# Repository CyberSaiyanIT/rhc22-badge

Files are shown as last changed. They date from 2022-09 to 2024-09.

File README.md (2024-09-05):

# RHC22 Badge

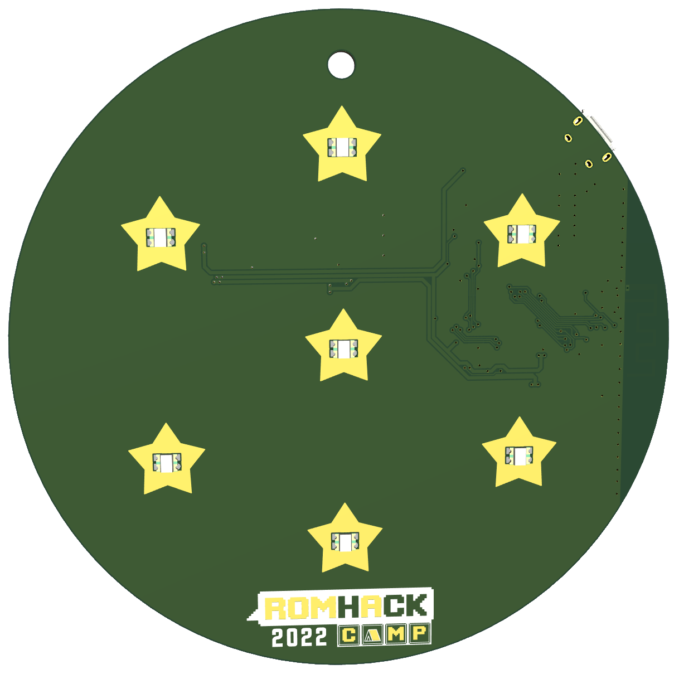
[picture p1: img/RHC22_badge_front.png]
RHC22 badge front

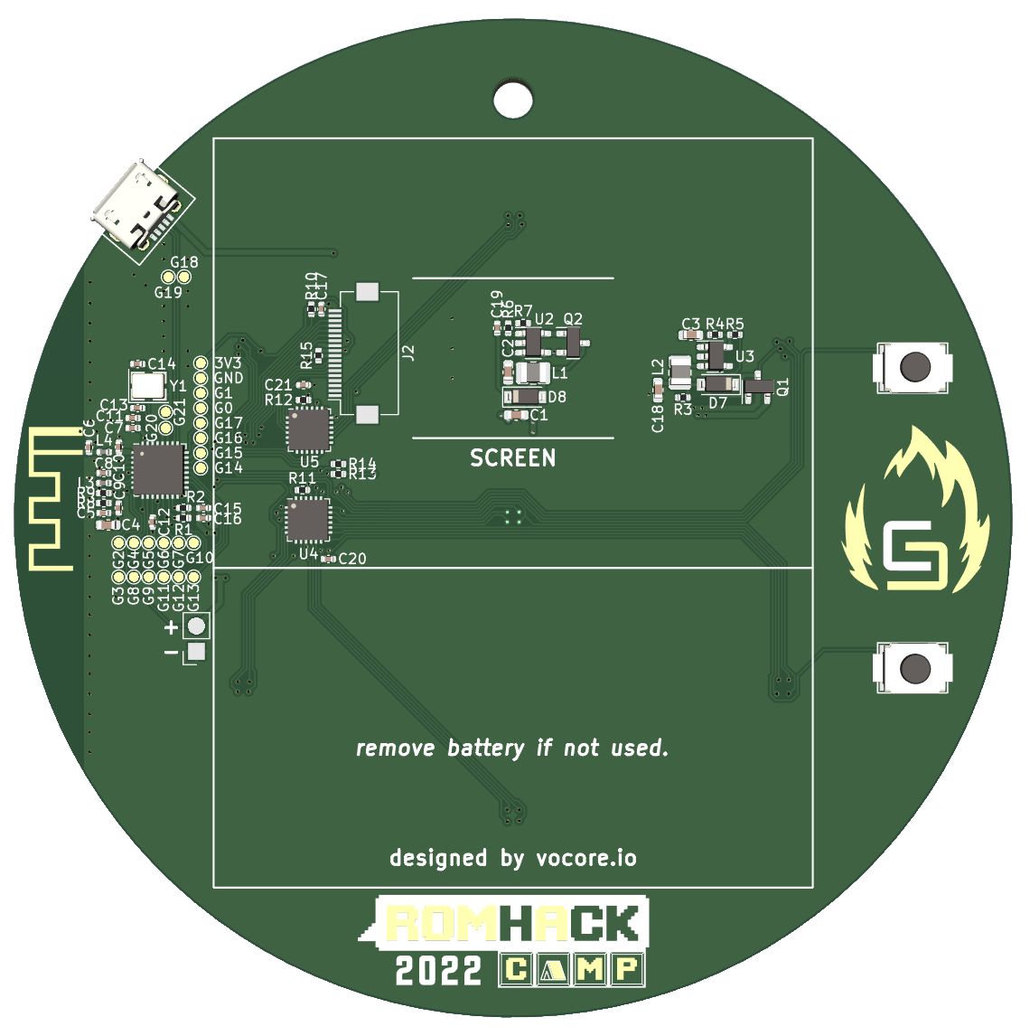
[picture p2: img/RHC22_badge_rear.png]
RHC22 badge rear


Cyber Saiyan community has designed and developed a special gadget to celebrate RomHack Camp 2022.

You can grab the badge by purchasing it at the Cyber Saiyan tent during the Camp and the Conference
* The badge's package will include a lanyard, two batteries and...the badge
* In order to start playing around with and hacking it, is recommended to bring a micro USB data cable with you
* It is also recommended to bring replacement 1.5V AA batteries and/or a powerbank
* The badge is already flashed with the Cyber Saiyan firmware
* We really will appreciate any improvement to the project and pull requests
* Don't hesitate to come and visit us at the Cyber Saiyan tent if you need help

## Features

The badge has some very simple features that will improve your Camp experience:
* It is designed to recall the dragon spheres (maybe you will be able to summon Shenron too)
* The base SOC is a single core ESP32-C3 
   * Integrates a 32-bit core RISC-V microcontroller with a maximum clock speed of 160 MHz
   * 22 configurable GPIOs
   * 400 KB of internal RAM and 4MB flash
   * WiFi and Bluetooth 5
* In the front there are 7 RGB leds
* In the back you have  
   * Two push buttons; use your nail for a better experience :)
   * A 2.4'' TFT screen 
   * A two AA battery holder

Once powered the badge will be assigned a 1-7 ID and will start to advertise itself using BLE and the screen will show the RomHack Camp 2022 logo 
* You can move to next/prev screen by a 1s long press
* The 1st screen is the RHC22 schedule: 
   * You will be able to read the schedule of the Camp (use the 4th screen to update it)
* The 2nd screen is the badges' radar: 
   * You will see all the badges around you in a dragon ball style
* The 3rd screen is the badge's list: 
   * You will see all the badges around you in a table view
* The 4th screen is for the WiFI functionalities: 
   * Start the AP mode and connect with your PC/smartphone in order to explore more functionalities
   * Start the schedule SYNC mode in order to update the schedule at the 2nd screen
* The 5th screen is for fun (you will be able to play with snake)

# Toolchain setup

## Prepare the environment 

### Visual Studio Code (VSCode)
Install Visual Studio Code as development environment:

* https://code.visualstudio.com/ - follow instructions there, if you don't have vscode yet.

### PlatformIO (PIO) extension
Install PlatformIO extension on Visual Studio Code:

* [Installation](http://docs.platformio.org/page/ide/vscode.html)
* [Quick Start](http://docs.platformio.org/page/ide/vscode.html#quick-start)
* [User Guide](http://docs.platformio.org/page/ide/vscode.html#user-guide)

Please follow to the official documentation [PlatformIO IDE for VSCode](http://docs.platformio.org/page/ide/vscode.html).

## Setup the project

* Git clone this repository and open it on VSCode

## Build www data (Linux)

* ./www-build.sh

## Build www data (Docker)

* Install docker
* docker build --pull --rm -f "Dockerfile" -t rhc22badge:latest "."
* (Bash) docker run -it -v <span>$</span>(pwd)/public:/public -v <span>$</span>(pwd)/data/www:/output rhc22badge
* (Powershell) docker run -it -v <span>$</span>{PWD}/public:/public -v <span>$</span>{PWD}/data/www:/output rhc22badge
   
## Build/Upload Filesystem

In order to upload the filesystem to the badge you need to plugin the badge using USB.
In the "Project Tasks" view of PIO navigate to:

* RHC22-Bagde
   * Platform
      * Build Filesystem Image
      * Upload Filesystem Image

## Build/Upload Firmware
In order to upload the firmware to the badge you need to plugin the badge using USB.
In the "Project Tasks" view of PIO navigate to:

* RHC22-Bagde
   * General
      * Build
      * Upload

# Known Issues
* after dowloading the MOCA schedule from web you should restart the badge to see the updated schedule. This is due to a memory allocartion problem (the json file is too big) and the fix is a WIP

# Misc

## Use a different logo image

To use a different logo first you need to 
* convert the BMP/JPG/PNG/SVG file to a C array; you can do this using an [online image converter](https://lvgl.io/tools/imageconverter) setting CF_TRUE_COLOR_ALPHA option
* adjust [main/badge/common/img_logo.c](main/badge/common/img_logo.c) file

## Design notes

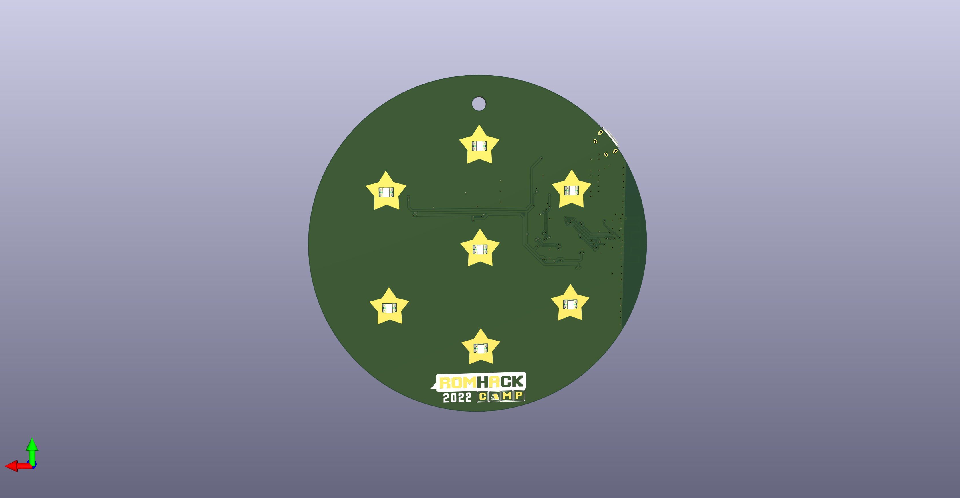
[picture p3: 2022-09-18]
hardware/dragon-front.png

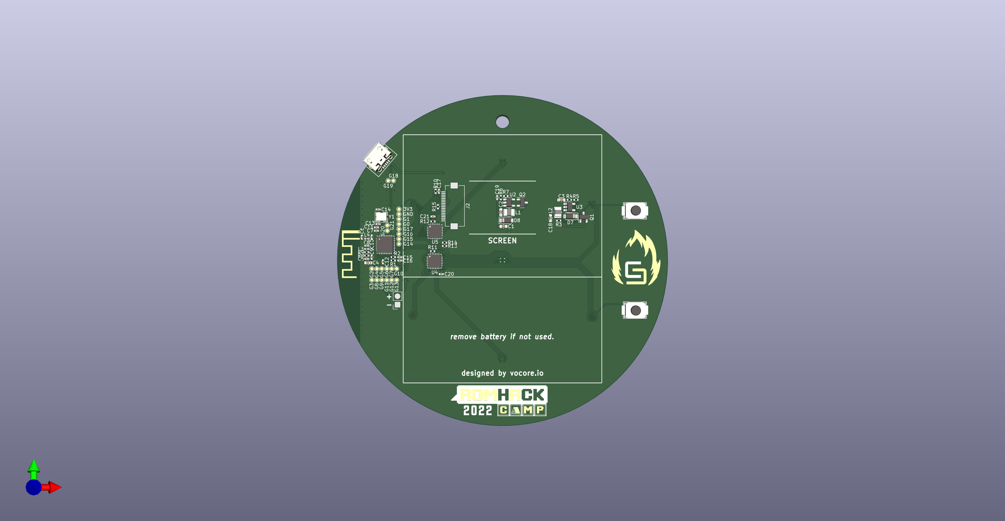
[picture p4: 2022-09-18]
hardware/dragon-back.png

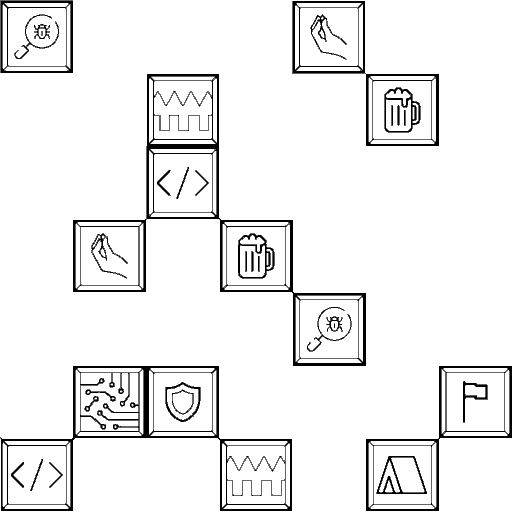
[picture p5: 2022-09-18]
public/img/sx.gif

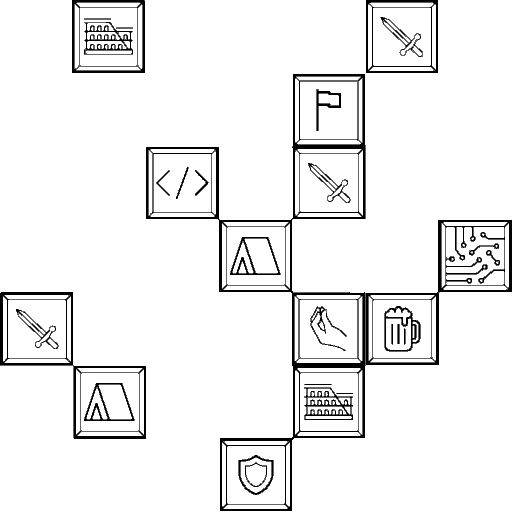
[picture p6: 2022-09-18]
public/img/dx.gif

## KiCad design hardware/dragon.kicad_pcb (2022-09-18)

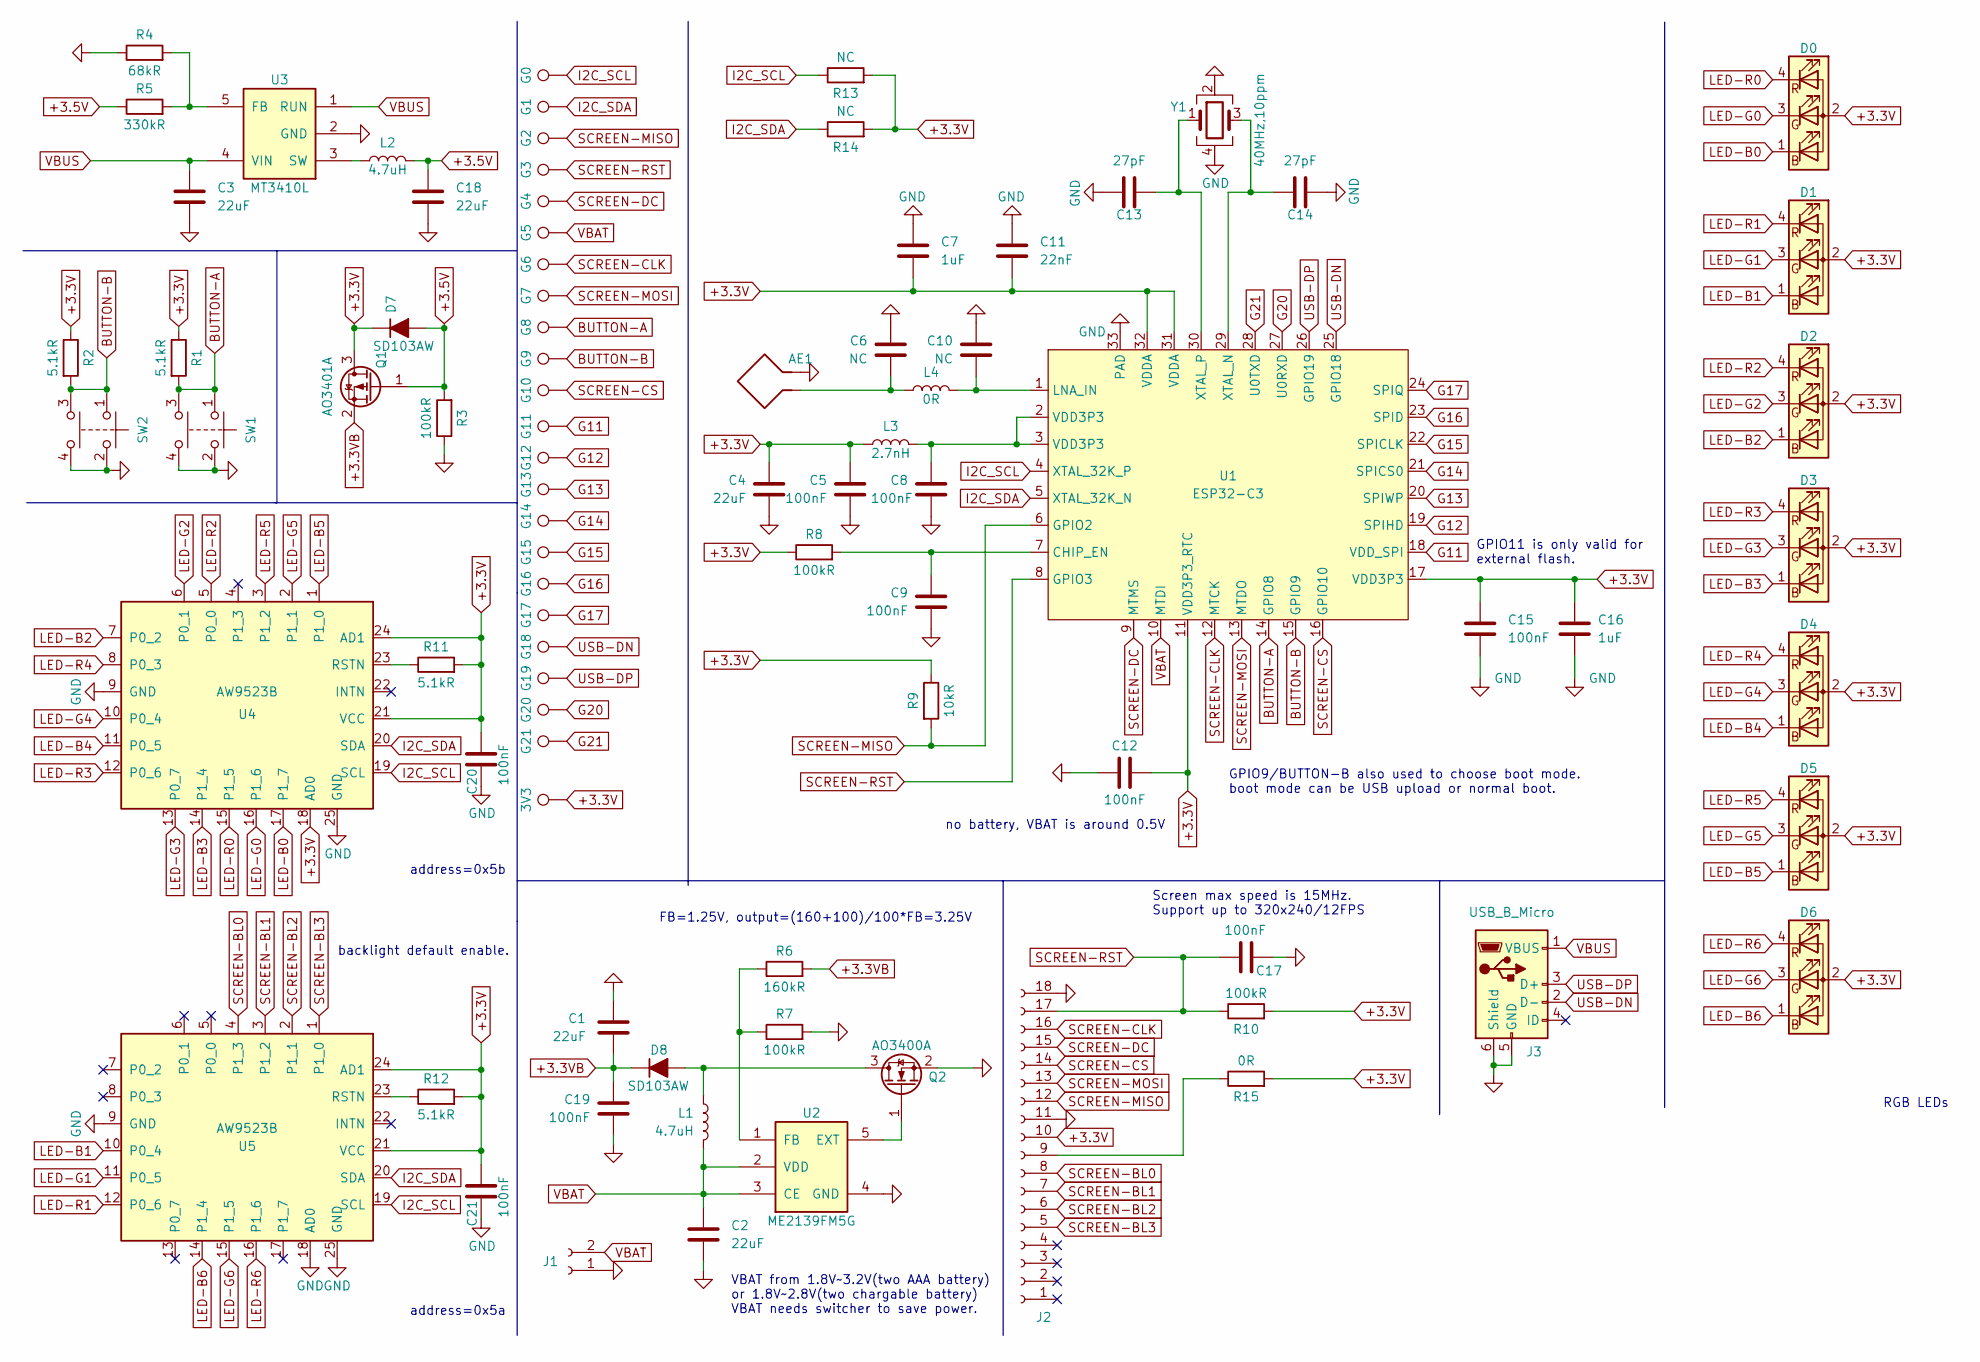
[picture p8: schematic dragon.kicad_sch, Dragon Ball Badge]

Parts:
3V3: TestPoint; TestPoint_Pad_D1.0mm
AE1: Antenna_Loop; Texas_SWRA117D_2.4GHz_Left
C1, C2, C3, C4, C18: 22uF; C_0603_1608Metric
C5, C8, C9, C12, C15, C17, C19, C20, C21: 100nF; C_0402_1005Metric
C6, C10: NC; C_0402_1005Metric
C7, C16: 1uF; C_0402_1005Metric
C11: 22nF; C_0402_1005Metric
C13, C14: 27pF; C_0402_1005Metric
D0, D1, D2, D3, D4, D5, D6: LED_BAGR
D7, D8: SD103AW; D_SOD-123
G0, G1, G2, G3, G4, G5, G6, G7, G8, G9, G10, G11, G12, G13, G14, G15, G16, G17, G18, G19, G20, G21: TestPoint; TestPoint_Pad_D1.0mm
J1: Conn_01x02_Female; PinSocket_1x02_P2.54mm_Vertical
J2: SCREEN; Hirose_FH12-18S-0.5SH_1x18-1MP_P0.50mm_Horizontal
J3: USB_B_Micro; USB_Micro-B
L1, L2: 4.7uH; L_1008_2520Metric
L3: 2.7nH; L_0402_1005Metric
L4: 0R; L_0402_1005Metric
Q1: AO3401A; SOT-23
Q2: AO3400A; SOT-23
R1, R2, R11, R12: 5.1kR; R_0402_1005Metric
R3, R7, R8, R10: 100kR; R_0402_1005Metric
R4: 68kR; R_0402_1005Metric
R5: 330kR; R_0402_1005Metric
R6: 160kR; R_0402_1005Metric
R9: 10kR; R_0402_1005Metric
R13, R14: NC; R_0402_1005Metric
R15: 0R; R_0402_1005Metric
SW1, SW2: SW_Push_Dual; BUTTON
U1: ESP32-C3; QFN-32-1EP_5x5mm_P0.5mm_EP3.1x3.1mm
U2: ME2139FM5G; SOT-23-5
U3: MT3410L; SOT-23-5
U4, U5: AW9523B; HVQFN-24-1EP_4x4mm_P0.5mm_EP2.6x2.6mm
Y1: 40MHz,10ppm; Crystal_SMD_3225-4Pin_3.2x2.5mm

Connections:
+3.3V: 3V3.1, C4.2, C5.2, C7.1, C11.1, C12.1, C15.2, C16.2, C20.2, C21.2, D0.2 (A), D1.2 (A), D2.2 (A), D3.2 (A), D4.2 (A), D5.2 (A), D6.2 (A), D7.1 (K), J2.10, L3.1, Q1.3 (D), R1.1, R2.1, R8.1, R9.1, R10.2, R11.2, R12.2, R13.2, R14.2, R15.2, U1.11 (VDD3P3_RTC), U1.17 (VDD3P3), U1.31 (VDDA), U1.32 (VDDA), U4.18 (AD0), U4.21 (VCC), U4.24 (AD1), U5.21 (VCC), U5.24 (AD1)
+3.3VB: C1.1, C19.2, D8.1 (K), Q1.2 (S), R6.2
+3.5V: C18.1, D7.2 (A), L2.2, Q1.1 (G), R3.2, R5.1
BUTTON-A: G8.1, R1.2, SW1.1, SW1.3, U1.14 (GPIO8)
BUTTON-B: G9.1, R2.2, SW2.1, SW2.3, U1.15 (GPIO9)
G11: G11.1, U1.18 (VDD_SPI)
G12: G12.1, U1.19 (SPIHD)
G13: G13.1, U1.20 (SPIWP)
G14: G14.1, U1.21 (SPICS0)
G15: G15.1, U1.22 (SPICLK)
G16: G16.1, U1.23 (SPID)
G17: G17.1, U1.24 (SPIQ)
G20: G20.1, U1.27 (U0RXD)
G21: G21.1, U1.28 (U0TXD)
GND: AE1.2, C1.2, C2.2, C3.2, C4.1, C5.1, C6.2, C7.2, C8.1, C9.1, C10.2, C11.2, C12.2, C13.1, C14.2, C15.1, C16.1, C17.2, C18.2, C19.1, C20.1, C21.1, J1.1, J2.11, J2.18, J3.5 (GND), J3.6 (Shield), Q2.2 (S), R3.1, R4.1, R7.2, SW1.2, SW1.4, SW2.2, SW2.4, U1.33 (PAD), U2.4 (GND), U3.2 (GND), U4.9 (GND), U4.25 (GND), U5.9 (GND), U5.18 (AD0), U5.25 (GND), Y1.2, Y1.4; also elsewhere on the board
I2C_SCL: G0.1, R13.1, U1.4 (XTAL_32K_P), U4.19 (SCL), U5.19 (SCL)
I2C_SDA: G1.1, R14.1, U1.5 (XTAL_32K_N), U4.20 (SDA), U5.20 (SDA)
LED-B0: D0.1 (BK), U4.17 (P1_7)
LED-B1: D1.1 (BK), U5.10 (P0_4)
LED-B2: D2.1 (BK), U4.7 (P0_2)
LED-B3: D3.1 (BK), U4.14 (P1_4)
LED-B4: D4.1 (BK), U4.11 (P0_5)
LED-B5: D5.1 (BK), U4.1 (P1_0)
LED-B6: D6.1 (BK), U5.14 (P1_4)
LED-G0: D0.3 (GK), U4.16 (P1_6)
LED-G1: D1.3 (GK), U5.11 (P0_5)
LED-G2: D2.3 (GK), U4.6 (P0_1)
LED-G3: D3.3 (GK), U4.13 (P0_7)
LED-G4: D4.3 (GK), U4.10 (P0_4)
LED-G5: D5.3 (GK), U4.2 (P1_1)
LED-G6: D6.3 (GK), U5.15 (P1_5)
LED-R0: D0.4 (RK), U4.15 (P1_5)
LED-R1: D1.4 (RK), U5.12 (P0_6)
LED-R2: D2.4 (RK), U4.5 (P0_0)
LED-R3: D3.4 (RK), U4.12 (P0_6)
LED-R4: D4.4 (RK), U4.8 (P0_3)
LED-R5: D5.4 (RK), U4.3 (P1_2)
LED-R6: D6.4 (RK), U5.16 (P1_6)
unnamed: AE1.1, C6.1, L4.1
unnamed: C8.2, L3.2, U1.2 (VDD3P3), U1.3 (VDD3P3)
unnamed: C9.2, R8.2, U1.7 (CHIP_EN)
unnamed: C10.1, L4.2, U1.1 (LNA_IN)
unnamed: C13.2, U1.30 (XTAL_P), Y1.1
unnamed: C14.1, U1.29 (XTAL_N), Y1.3
unnamed: D8.2 (A), L1.2, Q2.3 (D)
unnamed: J2.9, R15.1
unnamed: L2.1, U3.3 (SW)
unnamed: Q2.1 (G), U2.5 (EXT)
unnamed: R4.2, R5.2, U3.5 (FB)
unnamed: R6.1, R7.1, U2.1 (FB)
unnamed: R11.1, U4.23 (RSTN)
unnamed: R12.1, U5.23 (RSTN)
SCREEN-BL0: J2.8, U5.4 (P1_3)
SCREEN-BL1: J2.7, U5.3 (P1_2)
SCREEN-BL2: J2.6, U5.2 (P1_1)
SCREEN-BL3: J2.5, U5.1 (P1_0)
SCREEN-CLK: G6.1, J2.16, U1.12 (MTCK)
SCREEN-CS: G10.1, J2.14, U1.16 (GPIO10)
SCREEN-DC: G4.1, J2.15, U1.9 (MTMS)
SCREEN-MISO: G2.1, J2.12, R9.2, U1.6 (GPIO2)
SCREEN-MOSI: G7.1, J2.13, U1.13 (MTDO)
SCREEN-RST: C17.1, G3.1, J2.17, R10.1, U1.8 (GPIO3)
USB-DN: G18.1, J3.2 (D-), U1.25 (GPIO18)
USB-DP: G19.1, J3.3 (D+), U1.26 (GPIO19)
VBAT: C2.1, G5.1, J1.2, L1.1, U1.10 (MTDI), U2.2 (VDD), U2.3 (CE)
VBUS: C3.1, J3.1 (VBUS), U3.1 (RUN), U3.4 (VIN)

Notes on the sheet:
RGB LEDs
VBAT from 1.8V~3.2V(two AAA battery) or 1.8V~2.8V(two chargable battery) VBAT needs switcher to save power.
Screen max speed is 15MHz. Support up to 320x240/12FPS
FB=1.25V, output=(160+100)/100*FB=3.25V
no battery, VBAT is around 0.5V
GPIO9/BUTTON-B also used to choose boot mode. boot mode can be USB upload or normal boot.
address=0x5b
backlight default enable.
address=0x5a
GPIO11 is only valid for external flash.

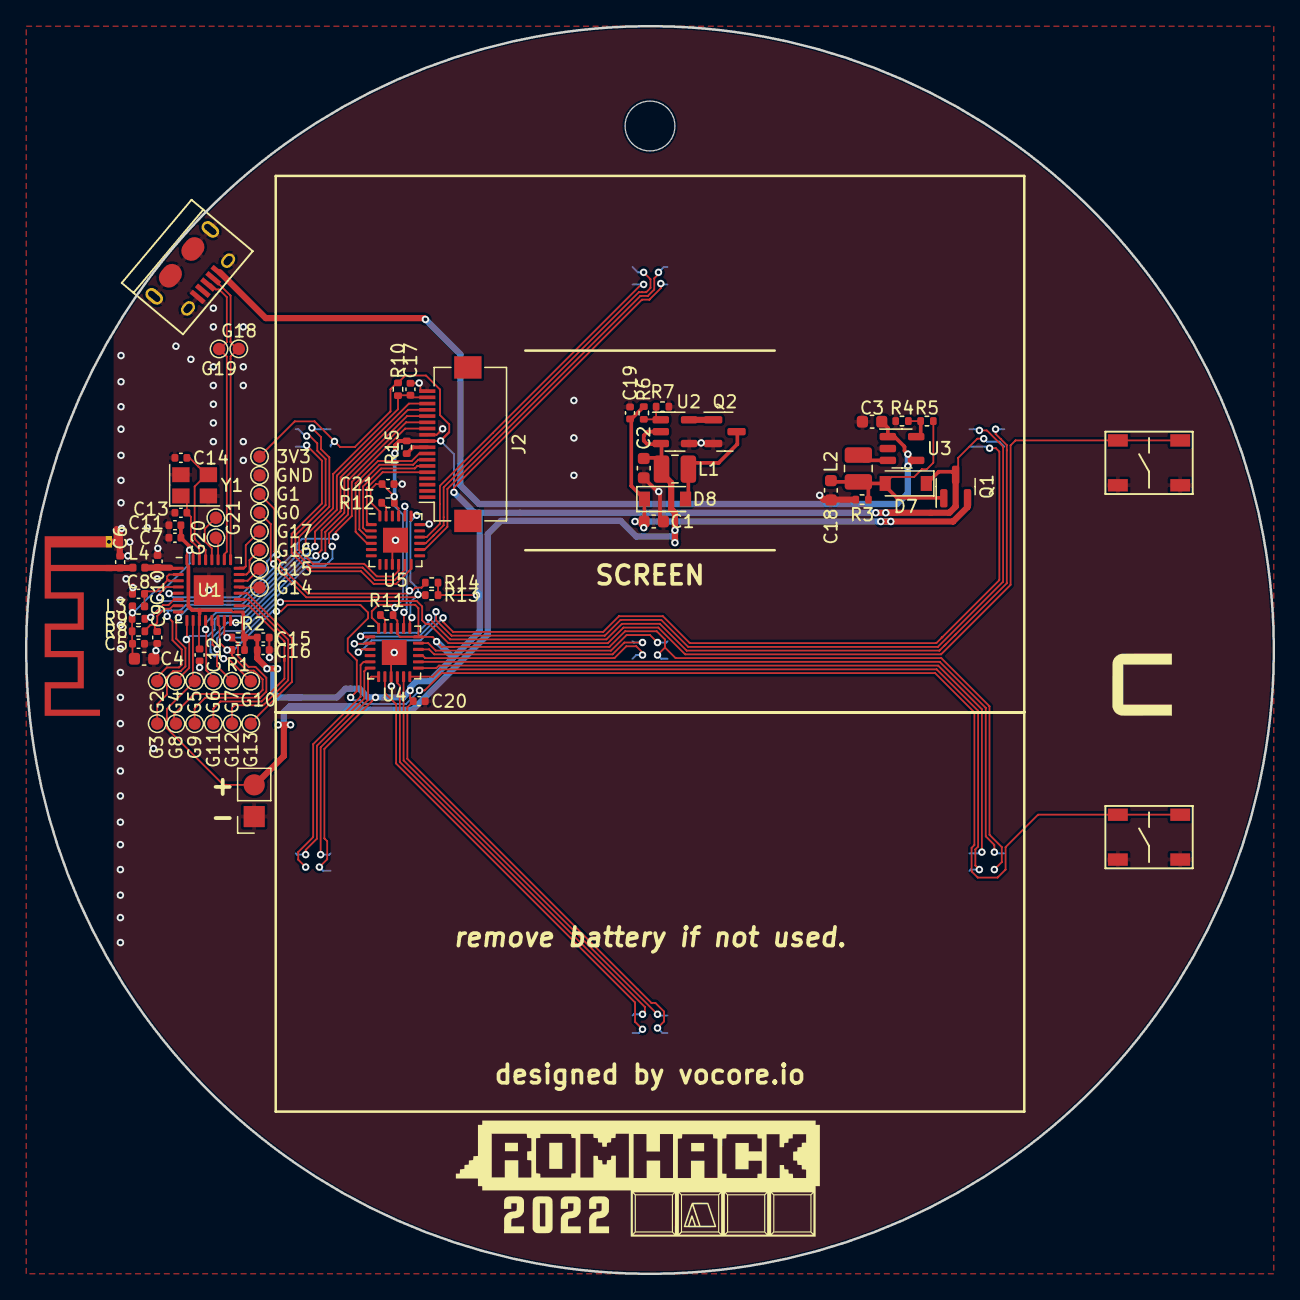
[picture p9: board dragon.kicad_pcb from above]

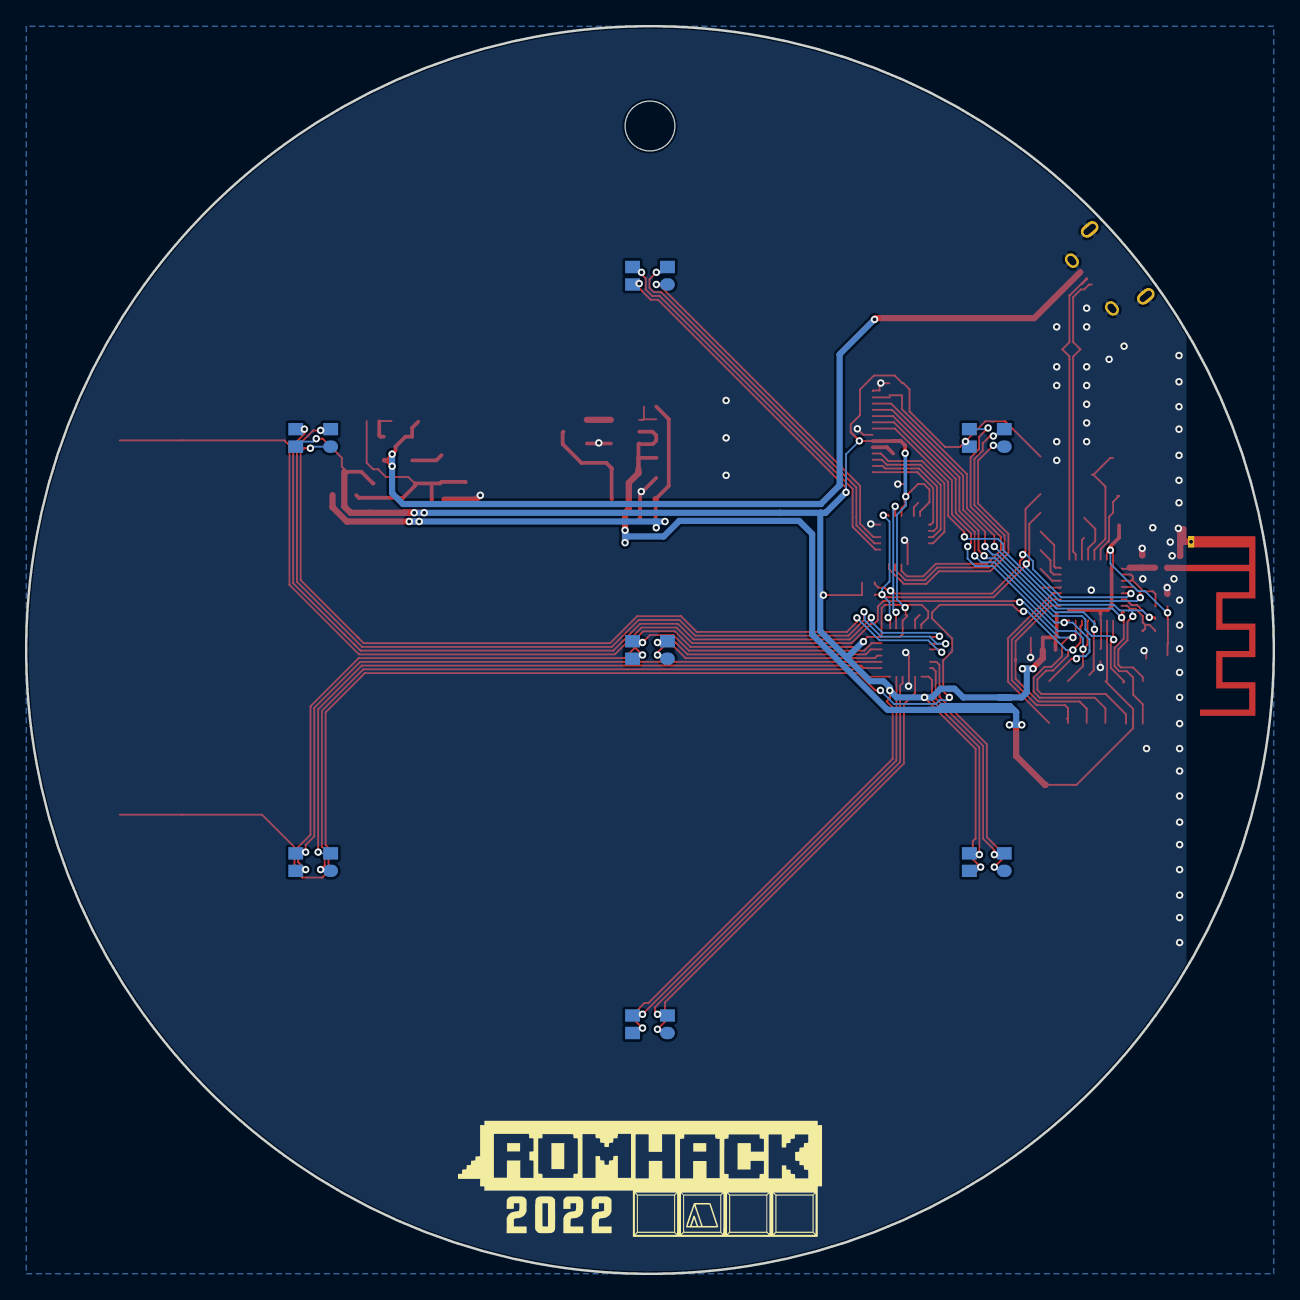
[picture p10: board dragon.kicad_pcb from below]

Board: 2 copper layers, 100.0 x 100.0 mm, 87 parts (7 on the bottom side), 66 nets.

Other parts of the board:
GND: TestPoint; TestPoint_Pad_D1.0mm

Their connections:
GND: GND.1; also elsewhere on the board

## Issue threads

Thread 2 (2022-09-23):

DOM-Based Stored Cross-Site Scripting (XSS)

smaury, 2022-09-23:
Hey there!
First of all the badge is amazing 🎉

While reading the code with my Shielder (@ShielderSec) fellows we spotted a DOM-Based Stored Cross-Site Scripting (XSS) in the web server frontend code.

## Description
When a user enables the badge access point it will spawn a web server and serve a page showing and allowing to edit some configurations and the nearby devices.
The frontend code is implemented here: https://github.com/CyberSaiyanIT/rhc22-badge/tree/master/public

When browsing the root of the web server the `index.js`, `client.js`, and `helper.js` are loaded: https://github.com/CyberSaiyanIT/rhc22-badge/blob/master/public/index.html#L161-L165

The `index.js` is the entrypoint and, among the others, calls the [`setupRadar()`](https://github.com/CyberSaiyanIT/rhc22-badge/blob/master/public/js/index.js#L151-L176), which calls the [`query_radar`](https://github.com/CyberSaiyanIT/rhc22-badge/blob/master/public/js/client.js#L41-L47) function which asks the badge the list of the badges nearby, and finally `setupRadar()` will add the badges information through the [`append_table()`](https://github.com/CyberSaiyanIT/rhc22-badge/blob/master/public/js/helpers.js#L61-L70) function, which finally used the [`generate_table()`](https://github.com/CyberSaiyanIT/rhc22-badge/blob/master/public/js/helpers.js#L47-L59) to create the HTML table body.

Now that the call flow is *we hope* clear, let's focus on the vulnerable vulnerable function:
```javascript
  function generate_table(table, data, row_keys) {
    let tbody = table.createTBody();
    for (let element of data) {
      let row = tbody.insertRow();
      row_keys.forEach(key =>{
        let cell = row.insertCell();
        let text = document.createTextNode(element[key]);
        cell.appendChild(text);
	cell.setAttribute("data-column", labels[key]);
        cell.innerHTML = element[key];
      });
    }
  }
```

People used to JavaScript would already have noticed the *smelly* usage of `innerHTML`. Setting the `innerHTML` attribute of an HTML element will basically replace the actual HTML code parsed by the browser, meaning that if you control what's set, then you could add arbitrary client-side code and ... run arbitrary JavaScript code 🎉

As we mentioned - what reaches the `generate_table` function as `data` argument is the information of remote badges advertising themselves via Bluetooth Low Energy (BLE). This means that the input is remote controllable by an attacker advertising their own badge :)

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

## Limitations

The max allowed name of a badge (that's a firmware limitation) is 24 bytes, 3 of them (the first ones) which should be `[$num]` where `$num` should be a number from 1 to 7.
Moreover, when a user connects to the badge through its AP, then they will have no internet connection.

This means that:
- We can't relay on remote resources (i.e. `<script src=//15.rs>`)
- We are limited to payloads working when set via `innerHTML` (i.e. no `<script>` tags, no `<svg onload=code()>`, etc.)
- We are limited to a 21 chars payload (i.e. `<style/onload=alert()>` will not work because it's one char too long :-/)

The only payload we came up with is the following and requires a click/tap to trigger: `[4]<svg/onclick=alert()>`

## Exploit (the easy way)
1. Grab an Android phone
2. Install the [nrf Connect app](https://play.google.com/store/apps/details?id=no.nordicsemi.android.mcp&hl=en&gl=US)
3. Rename your phone to `[4]<svg/onclick=alert()>`
4. In the app look for the packets of a real badge and clone it
5. Start advertising the cloned badge
6. Connect to a near-by badge via its AP
7. Open the web web server of the badge (http://192.168.4.1)
8. Browse the radar section
9. Notice a badge with an empty name but a large transparent square
10. Click / tap the big square
11. Notice the JavaScript pop-up (yes, it's the injected `alert()` being executed

## Exploit (the hard way)
1. Grab a Raspberry
2. Run the following commands as root:
```
hciconfig hci0 down
hciconfig hci0 up
hciconfig hci0 leadv 3
hciconfig hci0 noscan
hcitool -i hci0 cmd 0x08 0x0008 1d 02 01 02 19 09 5b 31 5d 3c 53 56 47 2f 6f  6e 63 6c 69 63 6b 3d 61 6c 65 72 74 28 29 3e
```
3. Connect to a near-by badge via its AP
4. Open the web web server of the badge (http://192.168.4.1)
5. Browse the radar section
6. Notice a badge with an empty name but a large transparent square
7. Click / tap the big square
8. Notice the JavaScript pop-up (yes, it's the injected `alert()` being executed

## Remediation
Replace `innerHTML` with `innerText`.

CyberSaiyanIT, 2022-09-27:
Thank you for reporting it.

Your report has been published in the repository [wiki](https://github.com/CyberSaiyanIT/rhc22-badge/wiki/DOM-Based-Stored-Cross-Site-Scripting-(XSS)-%5B1%5D).

Closed 2022-09-27.

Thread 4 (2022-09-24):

Tool www-build.sh for Windows

exbyte, 2022-09-24:
Convert the script from bash script to cmd or powershell script

CyberSaiyanIT, 2022-09-27:
We will include a Dockerfile to build www.

CyberSaiyanIT, 2022-10-02:
commit 536f222ae7debfd2c68159ee5222442498c3efb6 closes the issue

Closed 2022-10-02.

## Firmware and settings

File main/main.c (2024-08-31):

#include <stdio.h>
#include <string.h>

#include "badge/badge.h"

void app_main() 
{
    ESP_LOGI(__FILE__, "MAIN START: free_heap_size = %lu\n", esp_get_free_heap_size());

    badge_init();
    led_init();
    
    // start bluetooth
    bt_init();
    xTaskCreatePinnedToCore(bt_task, "bt_task", 4096, NULL, 6, NULL, 0);

    // start wifi management
    wifi_init();
    xTaskCreatePinnedToCore(wifi_task, "wifi_task", 4096, NULL, 5, NULL, 0);

    // start ui to core 1.
    xTaskCreatePinnedToCore(ui_task, "ui_task", 8192, NULL, 0, NULL, 1);

    xTaskCreatePinnedToCore(led_task, "led_task", 2048, NULL, 10, NULL, 0);

    xTaskCreatePinnedToCore(button_task, "button_task", 4096, NULL, 1, NULL, 0);

    // Handle HTTP webserver start/stop
    static httpd_handle_t server = NULL;
    ESP_ERROR_CHECK(esp_event_handler_register(IP_EVENT, IP_EVENT_AP_STAIPASSIGNED, &connect_handler, &server));
    ESP_ERROR_CHECK(esp_event_handler_register(WIFI_EVENT, WIFI_EVENT_AP_STADISCONNECTED, &disconnect_handler, &server));

    ESP_LOGI(__FILE__, "MAIN END: free_heap_size = %lu\n", esp_get_free_heap_size());
}

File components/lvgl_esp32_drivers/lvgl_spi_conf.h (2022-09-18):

/**
 * @file lvgl_spi_conf.h
 *
 */

#ifndef LVGL_SPI_CONF_H
#define LVGL_SPI_CONF_H

#ifdef __cplusplus
extern "C" {
#endif

/*********************
 *      INCLUDES
 *********************/

/*********************
 *      DEFINES
 *********************/
// DISPLAY PINS
#define DISP_SPI_MOSI CONFIG_LV_DISP_SPI_MOSI
#if defined (CONFIG_LV_DISPLAY_USE_SPI_MISO)
    #define DISP_SPI_MISO CONFIG_LV_DISP_SPI_MISO
    #define DISP_SPI_INPUT_DELAY_NS CONFIG_LV_DISP_SPI_INPUT_DELAY_NS
#else
    #define DISP_SPI_MISO (-1)
    #define DISP_SPI_INPUT_DELAY_NS (0)
#endif
#if defined(CONFIG_LV_DISP_SPI_IO2)
#define DISP_SPI_IO2 CONFIG_LV_DISP_SPI_IO2
#else
#define DISP_SPI_IO2 (-1)
#endif
#if defined(CONFIG_LV_DISP_SPI_IO3)
#define DISP_SPI_IO3 CONFIG_LV_DISP_SPI_IO3
#else
#define DISP_SPI_IO3 (-1)
#endif
#define DISP_SPI_CLK CONFIG_LV_DISP_SPI_CLK
#if defined (CONFIG_LV_DISPLAY_USE_SPI_CS)
    #define DISP_SPI_CS CONFIG_LV_DISP_SPI_CS
#else
    #define DISP_SPI_CS (-1)
#endif

/* Define TOUCHPAD PINS when selecting a touch controller */
#if !defined (CONFIG_LV_TOUCH_CONTROLLER_NONE)

/* Handle FT81X special case */
#if defined (CONFIG_LV_TFT_DISPLAY_CONTROLLER_FT81X) && \
    defined (CONFIG_LV_TOUCH_CONTROLLER_FT81X)

    #define TP_SPI_MOSI CONFIG_LV_DISP_SPI_MOSI
    #define TP_SPI_MISO CONFIG_LV_DISP_SPI_MISO
    #define TP_SPI_CLK  CONFIG_LV_DISP_SPI_CLK
    #define TP_SPI_CS   CONFIG_LV_DISP_SPI_CS
#else
    #define TP_SPI_MOSI CONFIG_LV_TOUCH_SPI_MOSI
    #define TP_SPI_MISO CONFIG_LV_TOUCH_SPI_MISO
    #define TP_SPI_CLK  CONFIG_LV_TOUCH_SPI_CLK
    #define TP_SPI_CS   CONFIG_LV_TOUCH_SPI_CS
#endif
#endif

#define ENABLE_TOUCH_INPUT  CONFIG_LV_ENABLE_TOUCH

#if defined (CONFIG_LV_TFT_DISPLAY_SPI_HSPI)
#if CONFIG_IDF_TARGET_ESP32C3
#define TFT_SPI_HOST SPI2_HOST
#else
#define TFT_SPI_HOST HSPI_HOST
#endif
#elif defined (CONFIG_LV_TFT_DISPLAY_SPI_VSPI)
#define TFT_SPI_HOST VSPI_HOST
#elif defined (CONFIG_LV_TFT_DISPLAY_SPI_FSPI)
#define TFT_SPI_HOST FSPI_HOST
#endif

#if defined (CONFIG_LV_TFT_DISPLAY_SPI_HALF_DUPLEX)
#define DISP_SPI_HALF_DUPLEX
#else
#define DISP_SPI_FULL_DUPLEX
#endif

#if defined (CONFIG_LV_TFT_DISPLAY_SPI_TRANS_MODE_DIO)
#define DISP_SPI_TRANS_MODE_DIO
#elif defined (CONFIG_LV_TFT_DISPLAY_SPI_TRANS_MODE_QIO)
#define DISP_SPI_TRANS_MODE_QIO
#else
#define DISP_SPI_TRANS_MODE_SIO
#endif

#if defined (CONFIG_LV_TOUCH_CONTROLLER_SPI_HSPI)
#define TOUCH_SPI_HOST HSPI_HOST
#elif defined (CONFIG_LV_TOUCH_CONTROLLER_SPI_VSPI)
#define TOUCH_SPI_HOST VSPI_HOST
#elif defined (CONFIG_LV_TOUCH_CONTROLLER_SPI_FSPI)
#define TOUCH_SPI_HOST FSPI_HOST
#endif

/* Handle the FT81X Special case */
#if defined (CONFIG_LV_TFT_DISPLAY_CONTROLLER_FT81X)

#if defined (CONFIG_LV_TOUCH_CONTROLLER_FT81X)
#define SHARED_SPI_BUS
#else
/* Empty */
#endif

#else
// Detect the use of a shared SPI Bus and verify the user specified the same SPI bus for both touch and tft
#if defined (CONFIG_LV_TOUCH_DRIVER_PROTOCOL_SPI) && TP_SPI_MOSI == DISP_SPI_MOSI && TP_SPI_CLK == DISP_SPI_CLK
#if TFT_SPI_HOST != TOUCH_SPI_HOST
#error You must specify the same SPI host (HSPI, VSPI or FSPI) for both display and touch driver
#endif

#define SHARED_SPI_BUS
#endif

#endif

/**********************
 *      TYPEDEFS
 **********************/
#if defined (CONFIG_LV_TFT_DISPLAY_CONTROLLER_ILI9481) || \
    defined (CONFIG_LV_TFT_DISPLAY_CONTROLLER_ILI9488)

#define SPI_BUS_MAX_TRANSFER_SZ (DISP_BUF_SIZE * 3)

#elif defined (CONFIG_LV_TFT_DISPLAY_CONTROLLER_ILI9341)  || \
      defined (CONFIG_LV_TFT_DISPLAY_CONTROLLER_ST7789)   || \
      defined (CONFIG_LV_TFT_DISPLAY_CONTROLLER_ST7735S)  || \
      defined (CONFIG_LV_TFT_DISPLAY_CONTROLLER_HX8357)   || \
      defined (CONFIG_LV_TFT_DISPLAY_CONTROLLER_SH1107)   || \
      defined (CONFIG_LV_TFT_DISPLAY_CONTROLLER_FT81X)    || \
      defined (CONFIG_LV_TFT_DISPLAY_CONTROLLER_IL3820)   || \
      defined (CONFIG_LV_TFT_DISPLAY_CONTROLLER_JD79653A)

#define SPI_BUS_MAX_TRANSFER_SZ (DISP_BUF_SIZE * 2)

#else
#define SPI_BUS_MAX_TRANSFER_SZ (DISP_BUF_SIZE * 2)
#endif

#if defined (CONFIG_LV_TFT_USE_CUSTOM_SPI_CLK_DIVIDER)
#define SPI_TFT_CLOCK_SPEED_HZ ((80 * 1000 * 1000) / CONFIG_LV_TFT_CUSTOM_SPI_CLK_DIVIDER)
#else
#if defined (CONFIG_LV_TFT_DISPLAY_CONTROLLER_ST7789)
#define SPI_TFT_CLOCK_SPEED_HZ  (20*1000*1000)
#elif defined (CONFIG_LV_TFT_DISPLAY_CONTROLLER_ST7735S)
#define SPI_TFT_CLOCK_SPEED_HZ  (40*1000*1000)
#elif defined (CONFIG_LV_TFT_DISPLAY_CONTROLLER_HX8357)
#define SPI_TFT_CLOCK_SPEED_HZ  (26*1000*1000)
#elif defined (CONFIG_LV_TFT_DISPLAY_CONTROLLER_SH1107)
#define SPI_TFT_CLOCK_SPEED_HZ  (8*1000*1000)
#elif defined (CONFIG_LV_TFT_DISPLAY_CONTROLLER_ILI9481)
#define SPI_TFT_CLOCK_SPEED_HZ  (16*1000*1000)
#elif defined (CONFIG_LV_TFT_DISPLAY_CONTROLLER_ILI9486)
#define SPI_TFT_CLOCK_SPEED_HZ  (20*1000*1000)
#elif defined (CONFIG_LV_TFT_DISPLAY_CONTROLLER_ILI9488)
#define SPI_TFT_CLOCK_SPEED_HZ  (40*1000*1000)
#elif defined (CONFIG_LV_TFT_DISPLAY_CONTROLLER_ILI9341)
#define SPI_TFT_CLOCK_SPEED_HZ  (40*1000*1000)
#elif defined (CONFIG_LV_TFT_DISPLAY_CONTROLLER_FT81X)
#define SPI_TFT_CLOCK_SPEED_HZ  (32*1000*1000)
#else
#define SPI_TFT_CLOCK_SPEED_HZ  (40*1000*1000)
#endif

#endif


#if defined (CONFIG_LV_TFT_DISPLAY_CONTROLLER_ST7789)
#define SPI_TFT_SPI_MODE    (2)
#else
#define SPI_TFT_SPI_MODE    (0)
#endif

/* Touch driver */
#if (CONFIG_LV_TOUCH_CONTROLLER == TOUCH_CONTROLLER_STMPE610)
#define SPI_TOUCH_CLOCK_SPEED_HZ    (1*1000*1000)
#define SPI_TOUCH_SPI_MODE          (1)
#else
#define SPI_TOUCH_CLOCK_SPEED_HZ    (2*1000*1000)
#define SPI_TOUCH_SPI_MODE          (0)
#endif

/**********************
 * GLOBAL PROTOTYPES
 **********************/


/**********************
 *      MACROS
 **********************/


#ifdef __cplusplus
} /* extern "C" */
#endif

#endif /*LVGL_SPI_CONF_H*/

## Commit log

2023-09-09 Customize badge firmware for ESC 2023 - reset wifi ssid&pwd - add ESC 2023 schedule to local fs - change logo to ESC logo - change sync url
2024-08-10 Fix for ESP platform version 5.4.0
    [button.c, led.c, main.c]
